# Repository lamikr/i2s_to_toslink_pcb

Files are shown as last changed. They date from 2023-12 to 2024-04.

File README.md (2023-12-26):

I2S to Toslink PCB

Kicad 7.0 schematic and PCB project for PCB that
can generate optical AES/EBU signal for Toslink audio adapter. PCB uses the
WM8805 chipset as a codec for transforming the signal from I2S to AES/EBU Toslink.

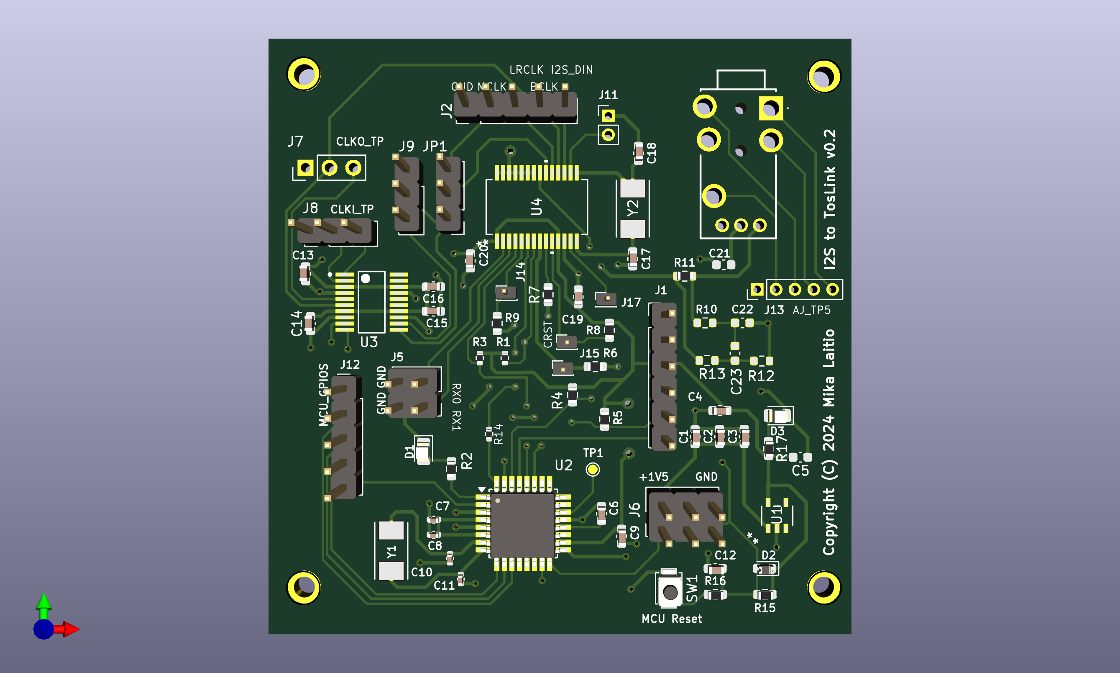
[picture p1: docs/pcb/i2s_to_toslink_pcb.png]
3D layout of PCB
 

PCB has following input pins:
- 5V power
- GND
- I2S data
- I2S LRCLK
- I2S BCLK
- I2S MCLK (optional)

PCB can either be configured to use the external MCLK or generate the MCLK from the BCLK.
Generation of MCLK is usually needed because the WM8805 does not always work with the external
MCLK and that is hearable as a small errors and cracks on audio.

Project will also need the firmware for ATmega chip so that it can configure the PLL generator
and WM8805 over I2C lines to right mode.

By default the WM8805 codec GPO0 and GPO7 are pulled down so that the WM8805 is configured to use 16 bit I2S data.
But those gpio's can be pulled also to UP to 3V3 voltage to configure the WM8805 to handle 24 bit I2S data if needed.
(see wm8805 docs for details). Codec can also be resetted externally via reset pin. (ATmega has free gpios with headers to drive those pins if you want to add the jumper wires and modify firmware)

[Schematics in PDF document](./docs/schematics/schematics.pdf)

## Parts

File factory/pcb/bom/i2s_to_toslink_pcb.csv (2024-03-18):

null | Sourced | Placed | References | Value | Footprint | Quantity
1 |  |  | C2, C4, C5, C6, C7, C8, C9, C12, C13, C14, C15, C16, C19, C20, C21 | 0u1F | C_0402_1005Metric | 15
2 | ✓ |  | C10, C11, C17, C18 | 16pF | C_0402_1005Metric | 4
3 | ✓ |  | C22, C23 | 0u1F | C_0603_1608Metric | 2
4 | ✓ |  | C1 | 4u7F | C_0402_1005Metric | 1
5 | ✓ |  | C3 | 1uF | C_0402_1005Metric | 1
6 | ✓ |  | R5, R6, R7, R8, R9 | 10k | R_0402_1005Metric | 5
7 | ✓ |  | R1, R3 | 4K7 | R_0402_1005Metric | 2
8 | ✓ |  | R10, R11 | 0 | R_0603_1608Metric | 2
9 | ✓ |  | R2 | 1K5 | R_0402_1005Metric | 1
10 | ✓ |  | R4 | 0k | R_0402_1005Metric | 1
11 | ✓ |  | R12 | 110 | R_0603_1608Metric | 1
12 | ✓ |  | R13 | 210 | R_0603_1608Metric | 1
13 |  |  | D1 | LED | LED_0805_2012Metric | 1
14 | ✓ |  | U1 | PTLV709A33DBVR | SOT-23-5_DBV_TEX | 1
15 | ✓ |  | U2 | ATmega168A-A | TQFP-32_7x7mm_P0.8mm | 1
16 |  |  | U3 | CDCE906PWR | PW0020A-IPC_A | 1
17 | ✓ |  | U4 | WM8805GEDS_V | SSOP28_WM8805GEDS_V_CIR | 1
18 |  |  | Y1 | 16M | XTAL_ABM7_ABR | 1
19 | ✓ |  | Y2 | 12M | XTAL_ABM7-12.000MHZ-D2Y-T | 1
20 |  |  | H1 | TL | MountingHole_2.2mm_M2_ISO7380_Pad_TopBottom | 1
21 |  |  | H2 | TR | MountingHole_2.2mm_M2_ISO7380_Pad_TopBottom | 1
22 |  |  | H3 | BL | MountingHole_2.2mm_M2_ISO7380_Pad_TopBottom | 1
23 |  |  | H4 | BR | MountingHole_2.2mm_M2_ISO7380_Pad_TopBottom | 1
24 |  |  | JP1 | MCLK_SEL | PinHeader_1x03_P2.54mm_Vertical | 1
25 |  |  | TP1 | TestPoint | TestPoint_Pad_D1.0mm | 1
26 |  |  | J1 | PWR IN | PinHeader_1x02_P2.54mm_Vertical | 1
27 |  |  | J2 | EXT_CLK_IN5 | PinHeader_1x05_P2.54mm_Vertical | 1
28 |  |  | J3 | PWR Test | PinHeader_1x03_P2.54mm_Vertical | 1
29 |  |  | J4 | MCU_GPIOS2 | PinHeader_1x03_P2.54mm_Vertical | 1
30 |  |  | J5 | FTDI_6P | PinHeader_1x06_P2.54mm_Vertical | 1
31 |  |  | J6 | AVR-ISP-6 | PinHeader_2x03_P2.54mm_Vertical | 1
32 |  |  | J7 | CLKI_3TP | PinHeader_1x03_P1.27mm_Vertical | 1
33 |  |  | J8 | SEL_3TP | PinHeader_1x03_P1.27mm_Vertical | 1
34 |  |  | J9 | CLKO_3TP | PinHeader_1x03_P1.27mm_Vertical | 1
35 | ✓ |  | J10 | FCR684204T | FCR684204T | 1
36 |  |  | J11 | DIN_DOUT_2TP | PinHeader_1x02_P1.27mm_Vertical | 1
37 |  |  | J12 | MCU_GPIOS1 | PinHeader_1x04_P2.54mm_Vertical | 1
38 |  |  | J13 | AJ_TP5 | PinHeader_1x05_P1.27mm_Vertical | 1
39 |  |  | J14 | C_G0 | PinHeader_1x01_P1.27mm_Vertical | 1
40 |  |  | J15 | C_G7 | PinHeader_1x01_P1.27mm_Vertical | 1
41 |  |  | J16 | C_RST | PinHeader_1x01_P1.27mm_Vertical | 1
42 |  |  | J17 | C_CLKOUT | PinHeader_1x01_P1.27mm_Vertical | 1

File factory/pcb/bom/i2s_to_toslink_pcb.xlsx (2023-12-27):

Reference | Value | Footprint | Datasheet | MFR | MPN | Notes | Price | QtyOrdered | SKU_DIGIKEY | Qty
C1 | 4u7F | Capacitor_SMD:C_0402_1005Metric | ~ | Murata | GRM155R60J475ME47D |  |  | 100 | 490-5915-1-ND | 1
C2, C4-C9, C12-C16, C19-C21 | 0u1F | Capacitor_SMD:C_0402_1005Metric | ~ | Murata | GRM033R61A104ME15D |  |  | 100 | 490-5405-1-ND | 15
C3 | 1uF | Capacitor_SMD:C_0402_1005Metric | ~ | Murata | GRM155R70J105KA12J |  |  | 100 | 490-13339-1-ND | 1
C10, C11, C17, C18 | 16pF | Capacitor_SMD:C_0402_1005Metric | ~ | Murata | GJM1555C1H160GB01D |  |  | 100 | 490-8081-1-ND | 4
C22, C23 | 0u1F | Capacitor_SMD:C_0603_1608Metric | ~ | Murata | GCJ188R71H104KA12D |  | 0.16 | 100 | 490-5798-1-ND | 2
J3 | PWR Test | Connector_PinHeader_2.54mm:PinHeader_1x03_P2.54mm_Vertical | ~ | Würth Elektronik | 61300311121 |  | 0.13 | 25 | 732-5316-ND | 1
J5 | FTDI_6P | Connector_PinHeader_2.54mm:PinHeader_1x06_P2.54mm_Vertical | ~ | Amphenol ICC | 10129378-920001BLF-ND | 1x20 | 0.43 | 10 | 10129378-920001BLF-ND | 1
J6 | AVR-ISP-6 | Connector_PinHeader_2.54mm:PinHeader_2x03_P2.54mm_Vertical | ~ | Amphenol ICC | 75869-131LF | 2x3 with plastic | 0.88 | 5 | 609-2845-ND | 1
J10 | FCR684204T | FCR684204T | ~ | CLIFF ELECTRONIC COMPONENTS | FCR684204T |  | 4.22 | 3 | 4654-FCR684204T-ND | 1
J11 | DIN_DOUT_2TP | Connector_PinHeader_1.27mm:PinHeader_1x02_P1.27mm_Vertical | ~ | Adam Tech | HPH1-A-20-UA | 1x20 pin header | 0.72 | 10 | 2057-HPH1-A-20-UA-ND | 1
J13 | AJ_TP5 | Connector_PinHeader_1.27mm:PinHeader_1x05_P1.27mm_Vertical | ~ | Sullins Connector Solutions | S9014E-05-ND |  | 0.4 | 10 | GRPB051VWVN-RC | 1
R1, R3 | 4K7 | Resistor_SMD:R_0402_1005Metric | ~ | Yageo | RC0402FR-074K7L |  | 0.1 | 100 | 311-4.7KLRCT-ND | 2
R2 | 1K5 | Resistor_SMD:R_0402_1005Metric | ~ | Yageo | RC0402FR-071K5L |  | 0.1 | 100 | 311-1.50KLRCT-ND | 1
R4 | 0k | Resistor_SMD:R_0402_1005Metric | ~ | Yageo | RC0402FR-070RL |  | 0.1 | 100 | 311-0.0LRCT-ND | 1
R5-R9 | 10k | Resistor_SMD:R_0402_1005Metric | ~ | Yageo | RC0402FR-0710KL |  | 0.1 | 100 | 311-10.0KLRCT-ND | 5
R10, R11 | 0 | Resistor_SMD:R_0603_1608Metric | ~ | Yageo | RC0603JR-070RL |  | 0.1 | 100 | 311-0.0GRCT-ND | 2
R12 | 110 | Resistor_SMD:R_0603_1608Metric | ~ | Yageo | RC0603JR-07110RL |  | 0.1 | 100 | 311-110GRCT-ND | 1
R13 | 210 | Resistor_SMD:R_0603_1608Metric | ~ | Yageo | RC0603FR-07210RL |  | 0.1 | 100 | 311-210HRCT-ND | 1
U1 | TLV709A33DBVR | SOT-23-5_DBV_TEX | ~ | TI | TLV709A33DBVR |  | 0.76 | 10 | 296-TLV709A33DBVRDKR-ND | 1
U2 | ATmega168A-A | Package_QFP:TQFP-32_7x7mm_P0.8mm | ~ | Microshell | ATMEGA168A-AUR |  | 2.36 | 3 | ATMEGA168A-AURCT-ND | 1
U3 | CDCE906PWR | PW0020A-IPC_A | ~ | TI | CDCE906PWR |  | 5.18 | 3 | 296-26038-1-ND | 1
U4 | WM8805GEDS_V | SSOP28_WM8805GEDS_V_CIR | ~ | Cirrus Logic | WM8805GEDS_V |  | 12 | 3 | 598-2396-ND | 1
Y1 | 16M | lamikr_audio:XTAL_ABM7_ABR | ~ | Abracon LLC | ABM7-16.000MHZ-D2Y-T |  | 0.67 | 10 | 535-9840-1-ND | 1
Y2 | 12M | lamikr_audio:XTAL_ABM7-12.000MHZ-D2Y-T | ~ | Abracon LLC | ABM7-12.000MHZ-D2Y-T |  | 0.67 | 10 | 535-9836-1-ND | 1

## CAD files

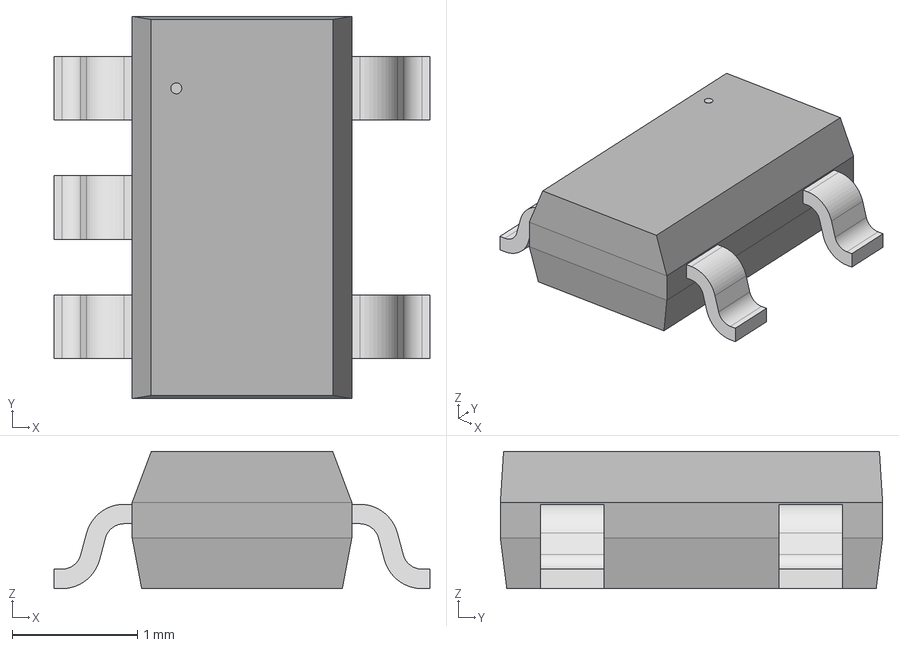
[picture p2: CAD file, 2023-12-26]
component_library/3dshapes/SOT-23-5_DBV_TEX.stp
3.00 x 3.05 x 1.09 mm

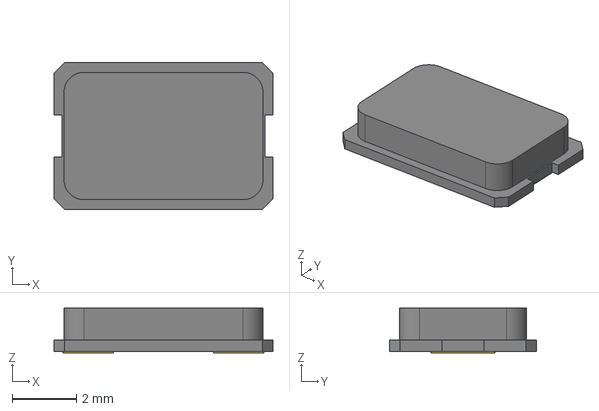
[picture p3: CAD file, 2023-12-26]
component_library/3dshapes/XTAL_ABM7_ABR.stp
6.82 x 4.58 x 1.40 mm

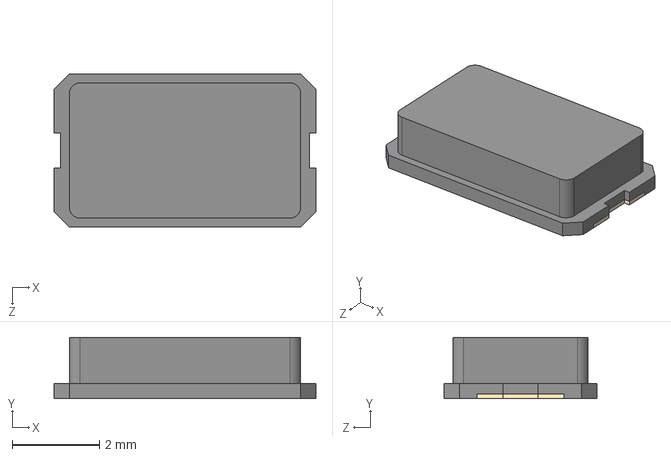
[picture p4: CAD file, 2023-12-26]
component_library/3dshapes/ABM7-12.000MHZ-D2Y-T.stp
6.00 x 1.40 x 3.50 mm

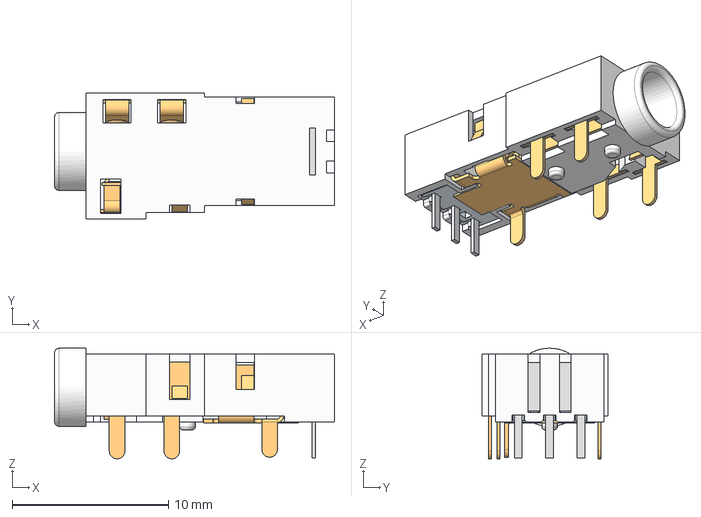
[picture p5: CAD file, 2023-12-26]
component_library/3dshapes/FCR684204T.stp
17.9 x 8.05 x 7.08 mm

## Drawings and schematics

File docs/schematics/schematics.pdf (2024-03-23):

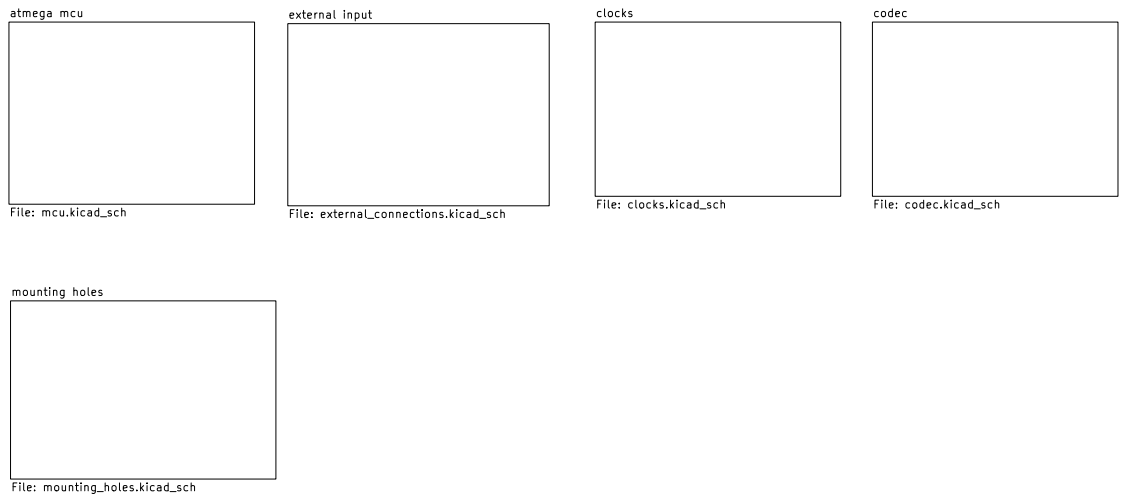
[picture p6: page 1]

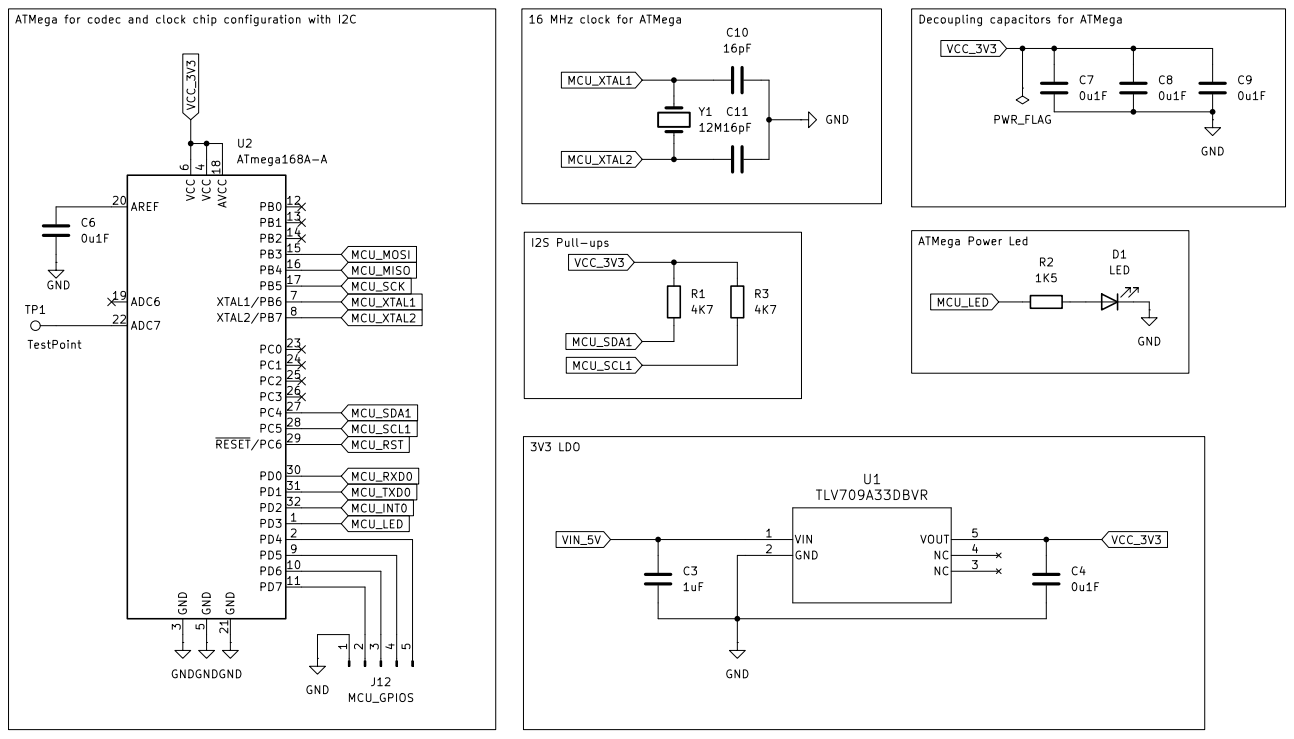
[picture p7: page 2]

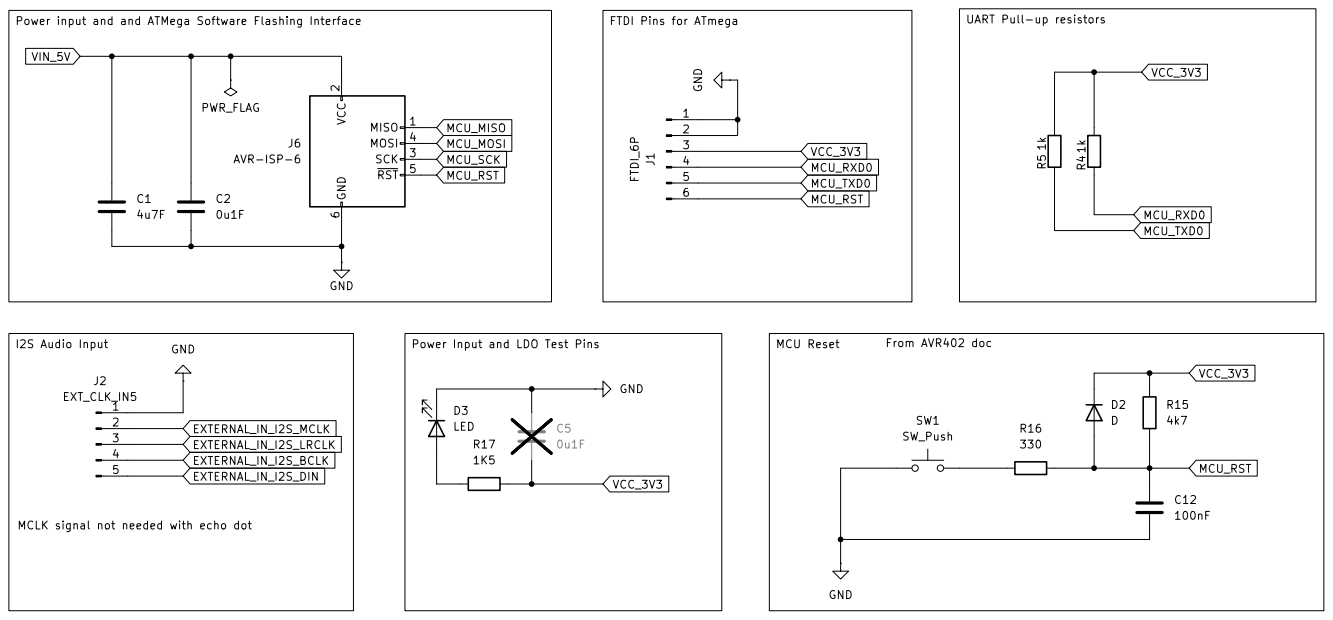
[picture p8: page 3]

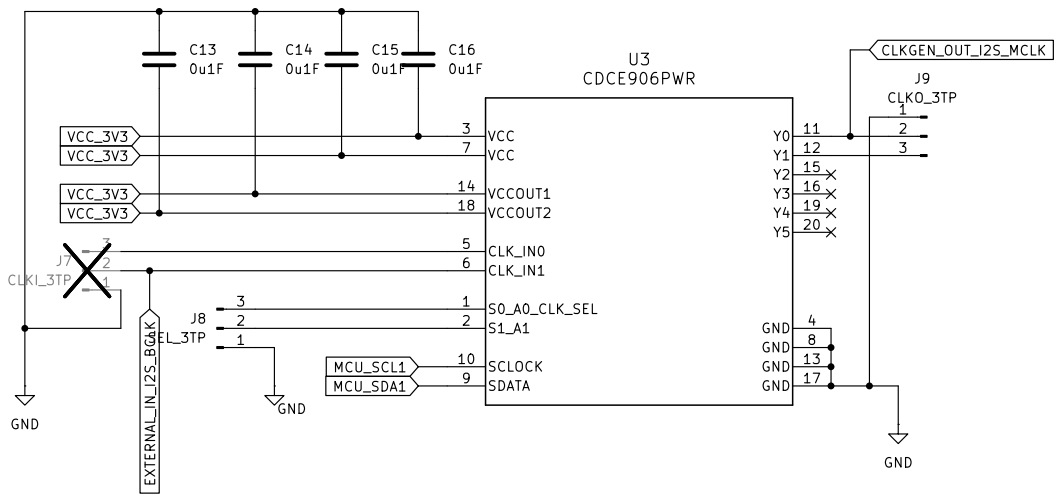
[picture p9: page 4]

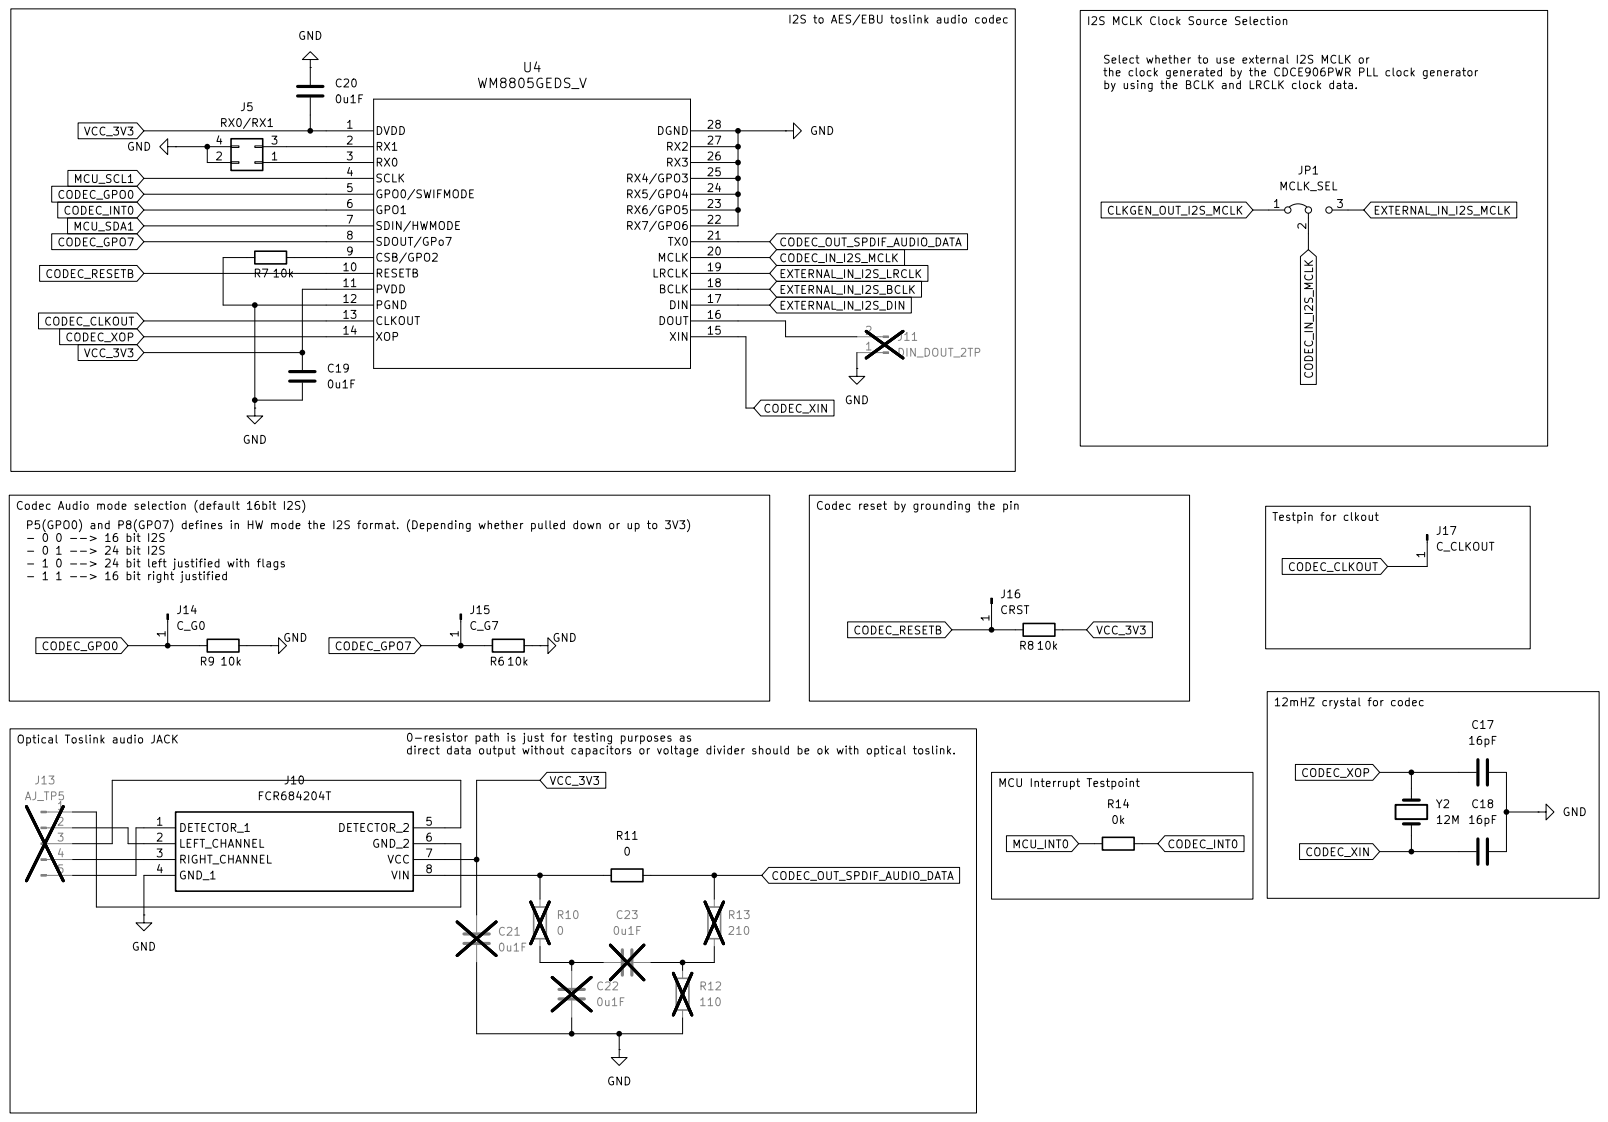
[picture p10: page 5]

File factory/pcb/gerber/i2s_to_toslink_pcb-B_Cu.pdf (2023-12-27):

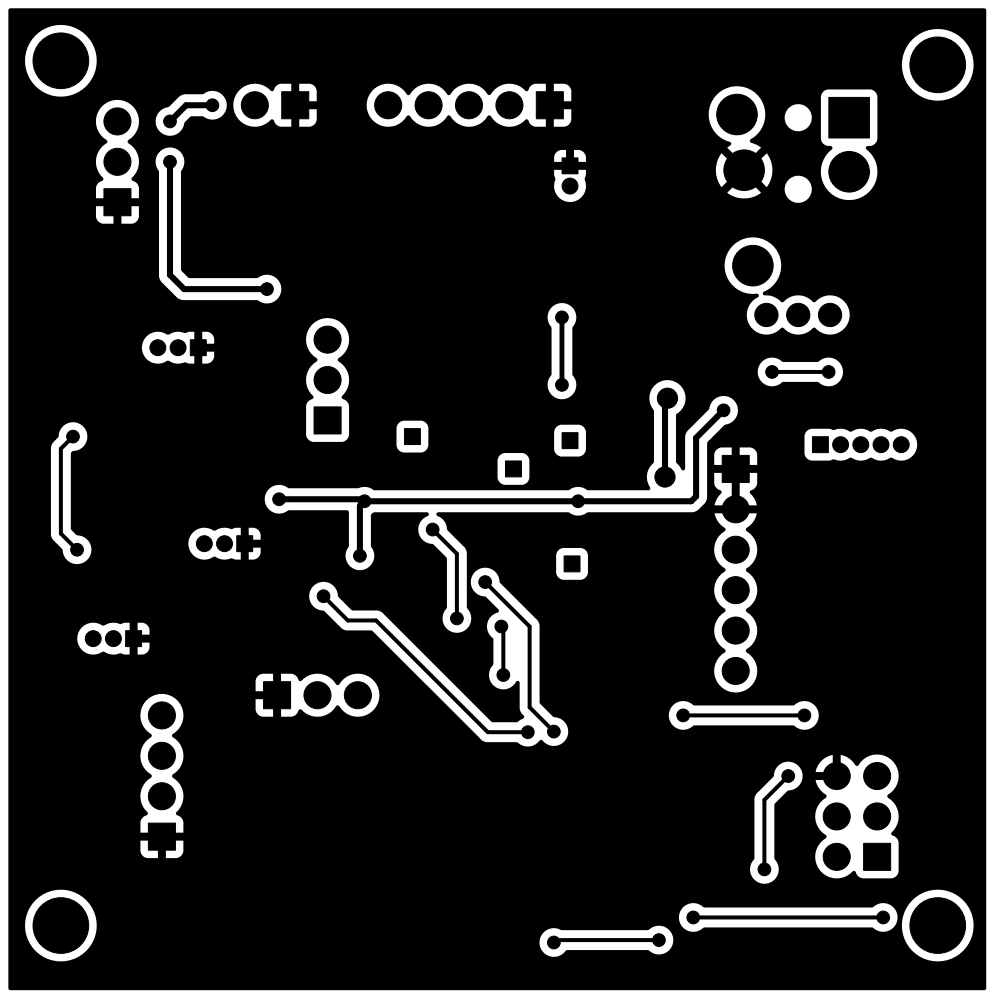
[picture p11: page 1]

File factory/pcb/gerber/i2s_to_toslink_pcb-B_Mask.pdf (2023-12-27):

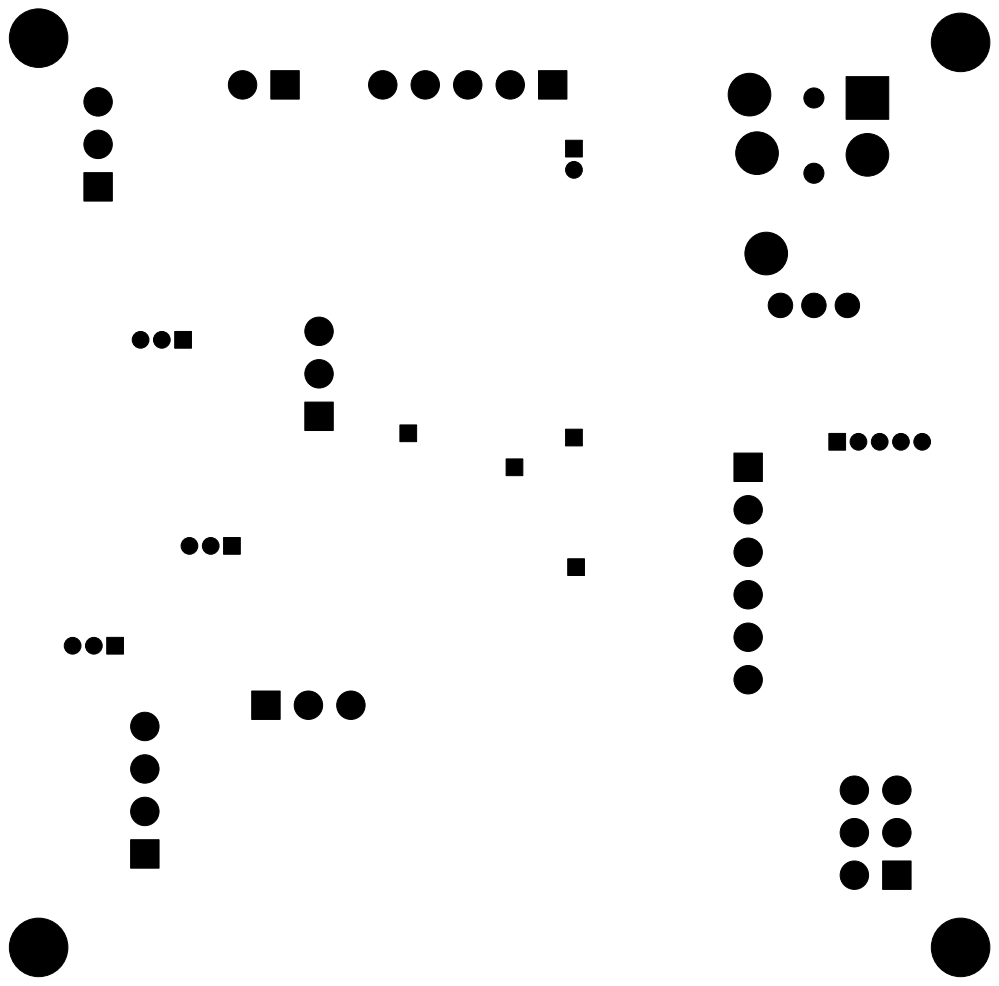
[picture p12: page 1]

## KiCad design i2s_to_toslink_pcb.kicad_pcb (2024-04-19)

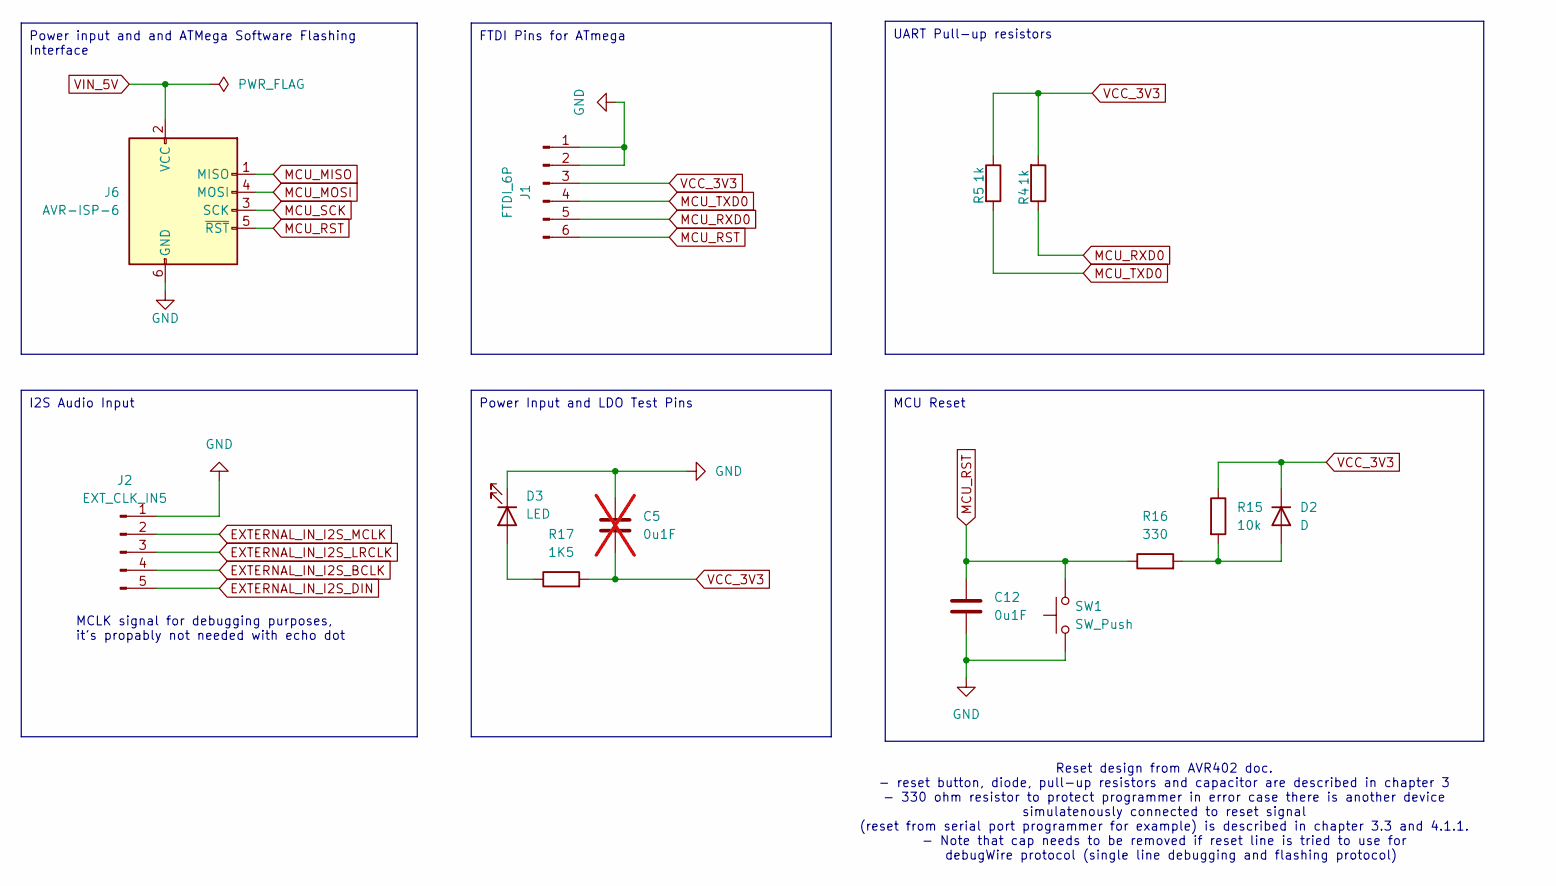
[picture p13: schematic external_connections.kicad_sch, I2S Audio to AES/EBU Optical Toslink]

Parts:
C5: 0u1F; C_0603_1608Metric; MPN GRM033R61A104ME15D; not fitted
C12: 0u1F; C_0603_1608Metric
D2: D; D_0603_1608Metric
D3: LED; LED_0805_2012Metric; MPN QBLP631-AG
J1: FTDI_6P; PinHeader_1x06_P2.54mm_Vertical; MPN 10129378-920001BLF-ND
J2: EXT_CLK_IN5; PinHeader_1x05_P2.54mm_Vertical
J6: AVR-ISP-6; PinHeader_2x03_P2.54mm_Vertical; MPN 75869-131LF
R4: 1k; R_0603_1608Metric; MPN RC0402FR-0710KL
R5: 1k; R_0603_1608Metric; MPN RC0402FR-070RL
R15: 10k; R_0603_1608Metric
R16: 330; R_0603_1608Metric
R17: 1K5; R_0603_1608Metric; MPN RC0402FR-071K5L
SW1: SW_Push; SW_SPST_B3U-1000P

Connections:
EXTERNAL_IN_I2S_BCLK: J2.4; also elsewhere on the board
EXTERNAL_IN_I2S_DIN: J2.5; also elsewhere on the board
EXTERNAL_IN_I2S_LRCLK: J2.3; also elsewhere on the board
EXTERNAL_IN_I2S_MCLK: J2.2; also elsewhere on the board
GND: C5.1, C12.2, D3.1 (K), J1.1, J1.2, J2.1, J6.6 (GND), SW1.1; also elsewhere on the board
MCU_MISO: J6.1 (MISO); also elsewhere on the board
MCU_MOSI: J6.4 (MOSI); also elsewhere on the board
MCU_RST: C12.1, J1.6, J6.5 (~RST), R16.1, SW1.2; also elsewhere on the board
MCU_RXD0: J1.5, R4.1; also elsewhere on the board
MCU_SCK: J6.3 (SCK); also elsewhere on the board
MCU_TXD0: J1.4, R5.2; also elsewhere on the board
unnamed: D2.2 (A), R15.2, R16.2
unnamed: D3.2 (A), R17.1
VCC_3V3: C5.2, D2.1 (K), J1.3, R4.2, R5.1, R15.1, R17.2; also elsewhere on the board
VIN_5V: J6.2 (VCC); also elsewhere on the board

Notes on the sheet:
Power input and and ATMega Software Flashing Interface
MCU Reset
UART Pull-up resistors
FTDI Pins for ATmega
I2S Audio Input
Power Input and LDO Test Pins
MCLK signal for debugging purposes, it's propably not needed with echo dot
Reset design from AVR402 doc. - reset button, diode, pull-up resistors and capacitor are described in chapter 3 - 330 ohm resistor to protect programmer in error case there is another device simulatenously connected to reset signal (reset from serial port programmer for example) is described in cha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

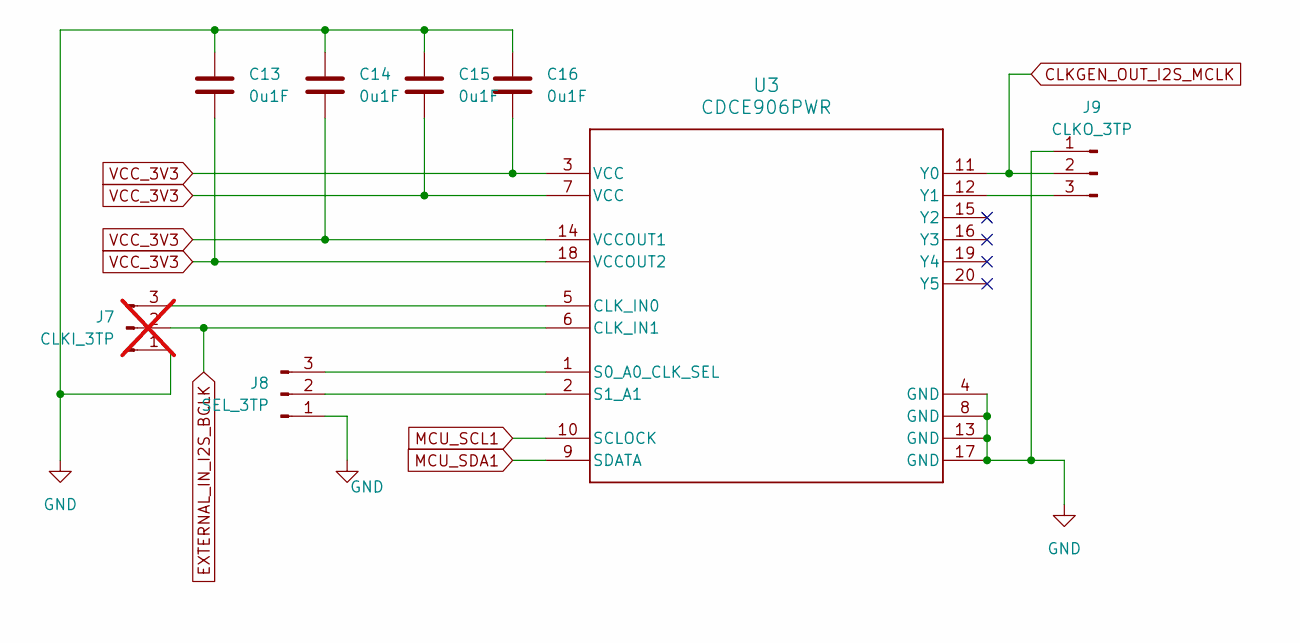
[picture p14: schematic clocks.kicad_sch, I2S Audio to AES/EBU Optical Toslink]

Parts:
C13, C14, C15, C16: 0u1F; C_0603_1608Metric; MPN GRM033R61A104ME15D
J7: CLKI_3TP; PinHeader_1x03_P2.54mm_Vertical; not fitted
J8: SEL_3TP; PinHeader_1x03_P2.54mm_Vertical
J9: CLKO_3TP; PinHeader_1x03_P2.54mm_Vertical
U3: CDCE906PWR; PW0020A-IPC_A; MPN CDCE906PWR

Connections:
CLKGEN_OUT_I2S_MCLK: J9.2, U3.11 (Y0); also elsewhere on the board
EXTERNAL_IN_I2S_BCLK: J7.2, U3.6 (CLK_IN1); also elsewhere on the board
GND: C13.1, C14.1, C15.1, C16.1, J7.1, J8.1, J9.1, U3.4 (GND), U3.8 (GND), U3.13 (GND), U3.17 (GND); also elsewhere on the board
MCU_SCL1: U3.10 (SCLOCK); also elsewhere on the board
MCU_SDA1: U3.9 (SDATA); also elsewhere on the board
unnamed: J7.3, U3.5 (CLK_IN0)
unnamed: J8.2, U3.2 (S1_A1)
unnamed: J8.3, U3.1 (S0_A0_CLK_SEL)
unnamed: J9.3, U3.12 (Y1)
VCC_3V3: C13.2, C14.2, C15.2, C16.2, U3.3 (VCC), U3.7 (VCC), U3.14 (VCCOUT1), U3.18 (VCCOUT2); also elsewhere on the board

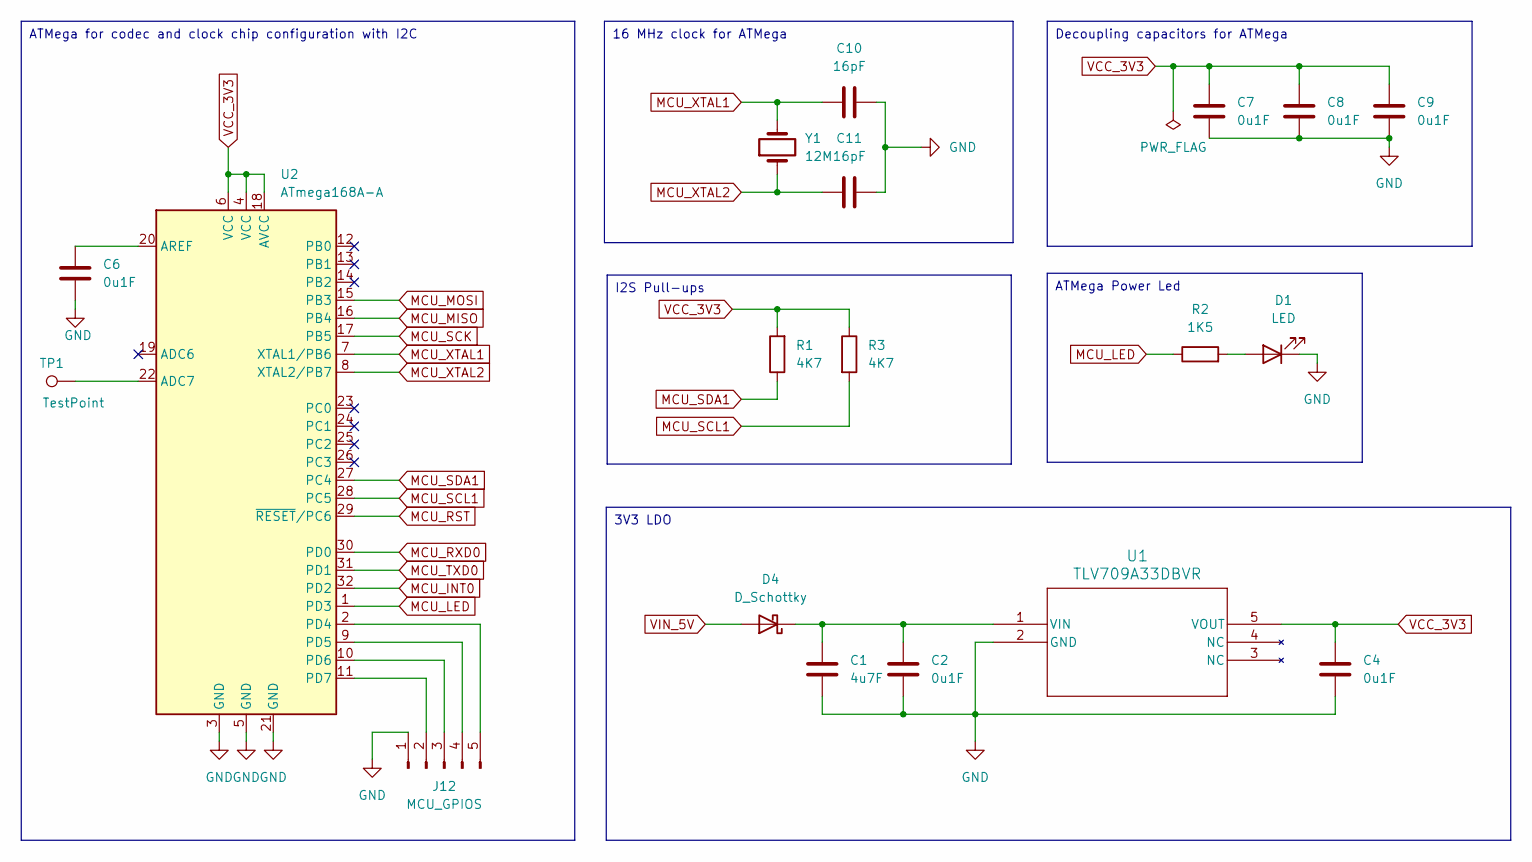
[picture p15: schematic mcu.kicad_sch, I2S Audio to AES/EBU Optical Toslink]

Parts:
C1: 4u7F; C_0603_1608Metric; MPN GRM155R60J475ME47D
C2, C4, C6, C7, C8, C9: 0u1F; C_0603_1608Metric; MPN GRM033R61A104ME15D
C10, C11: 16pF; C_0402_1005Metric; MPN GJM1555C1H160GB01D
D1: LED; LED_0805_2012Metric; MPN QBLP631-AG
D4: D_Schottky; D_0603_1608Metric
J12: MCU_GPIOS; PinHeader_1x05_P2.54mm_Vertical
R1, R3: 4K7; R_0603_1608Metric; MPN RC0402FR-074K7L
R2: 1K5; R_0603_1608Metric; MPN RC0402FR-071K5L
TP1: TestPoint; TestPoint_Pad_D1.0mm
U1: TLV709A33DBVR; SOT-23-5_DBV_TEX; MPN TLV709A33DBVR
U2: ATmega168A-A; TQFP-32_7x7mm_P0.8mm; MPN ATMEGA168A-AUR
Y1: 12M; XTAL_ABM7-12.000MHZ-D2Y-T; MPN ABM7-12.000MHZ-D2Y-T

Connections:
GND: C1.2, C2.2, C4.2, C6.2, C7.2, C8.2, C9.2, C10.2, C11.2, D1.1 (K), J12.1, U1.2 (GND), U2.3 (GND), U2.5 (GND), U2.21 (GND); also elsewhere on the board
MCU_INT0: U2.32 (PD2); also elsewhere on the board
MCU_LED: R2.1, U2.1 (PD3)
MCU_MISO: U2.16 (PB4); also elsewhere on the board
MCU_MOSI: U2.15 (PB3); also elsewhere on the board
MCU_RST: U2.29 (~RESET/PC6); also elsewhere on the board
MCU_RXD0: U2.30 (PD0); also elsewhere on the board
MCU_SCK: U2.17 (PB5); also elsewhere on the board
MCU_SCL1: R3.2, U2.28 (PC5); also elsewhere on the board
MCU_SDA1: R1.1, U2.27 (PC4); also elsewhere on the board
MCU_TXD0: U2.31 (PD1); also elsewhere on the board
MCU_XTAL1: C10.1, U2.7 (XTAL1/PB6), Y1.2
MCU_XTAL2: C11.1, U2.8 (XTAL2/PB7), Y1.1
unnamed: D1.2 (A), R2.2
unnamed: C1.1, C2.1, D4.1 (K), U1.1 (VIN)
unnamed: J12.2, U2.11 (PD7)
unnamed: J12.3, U2.10 (PD6)
unnamed: J12.4, U2.9 (PD5)
unnamed: J12.5, U2.2 (PD4)
unnamed: TP1.1, U2.22 (ADC7)
unnamed: C6.1, U2.20 (AREF)
VCC_3V3: C4.1, C7.1, C8.1, C9.1, R1.2, R3.1, U1.5 (VOUT), U2.4 (VCC), U2.6 (VCC), U2.18 (AVCC); also elsewhere on the board
VIN_5V: D4.2 (A); also elsewhere on the board

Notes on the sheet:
16 MHz clock for ATMega
ATMega for codec and clock chip configuration with I2C
ATMega Power Led
I2S Pull-ups
3V3 LDO
Decoupling capacitors for ATMega

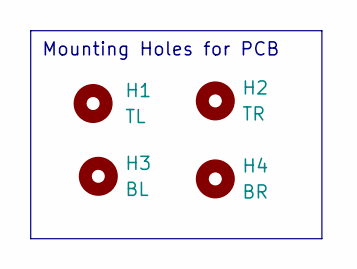
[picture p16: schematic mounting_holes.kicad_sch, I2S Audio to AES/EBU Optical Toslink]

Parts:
H1: TL; MountingHole_2.2mm_M2_ISO7380_Pad_TopBottom
H2: TR; MountingHole_2.2mm_M2_ISO7380_Pad_TopBottom
H3: BL; MountingHole_2.2mm_M2_ISO7380_Pad_TopBottom
H4: BR; MountingHole_2.2mm_M2_ISO7380_Pad_TopBottom

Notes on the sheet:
Mounting Holes for PCB

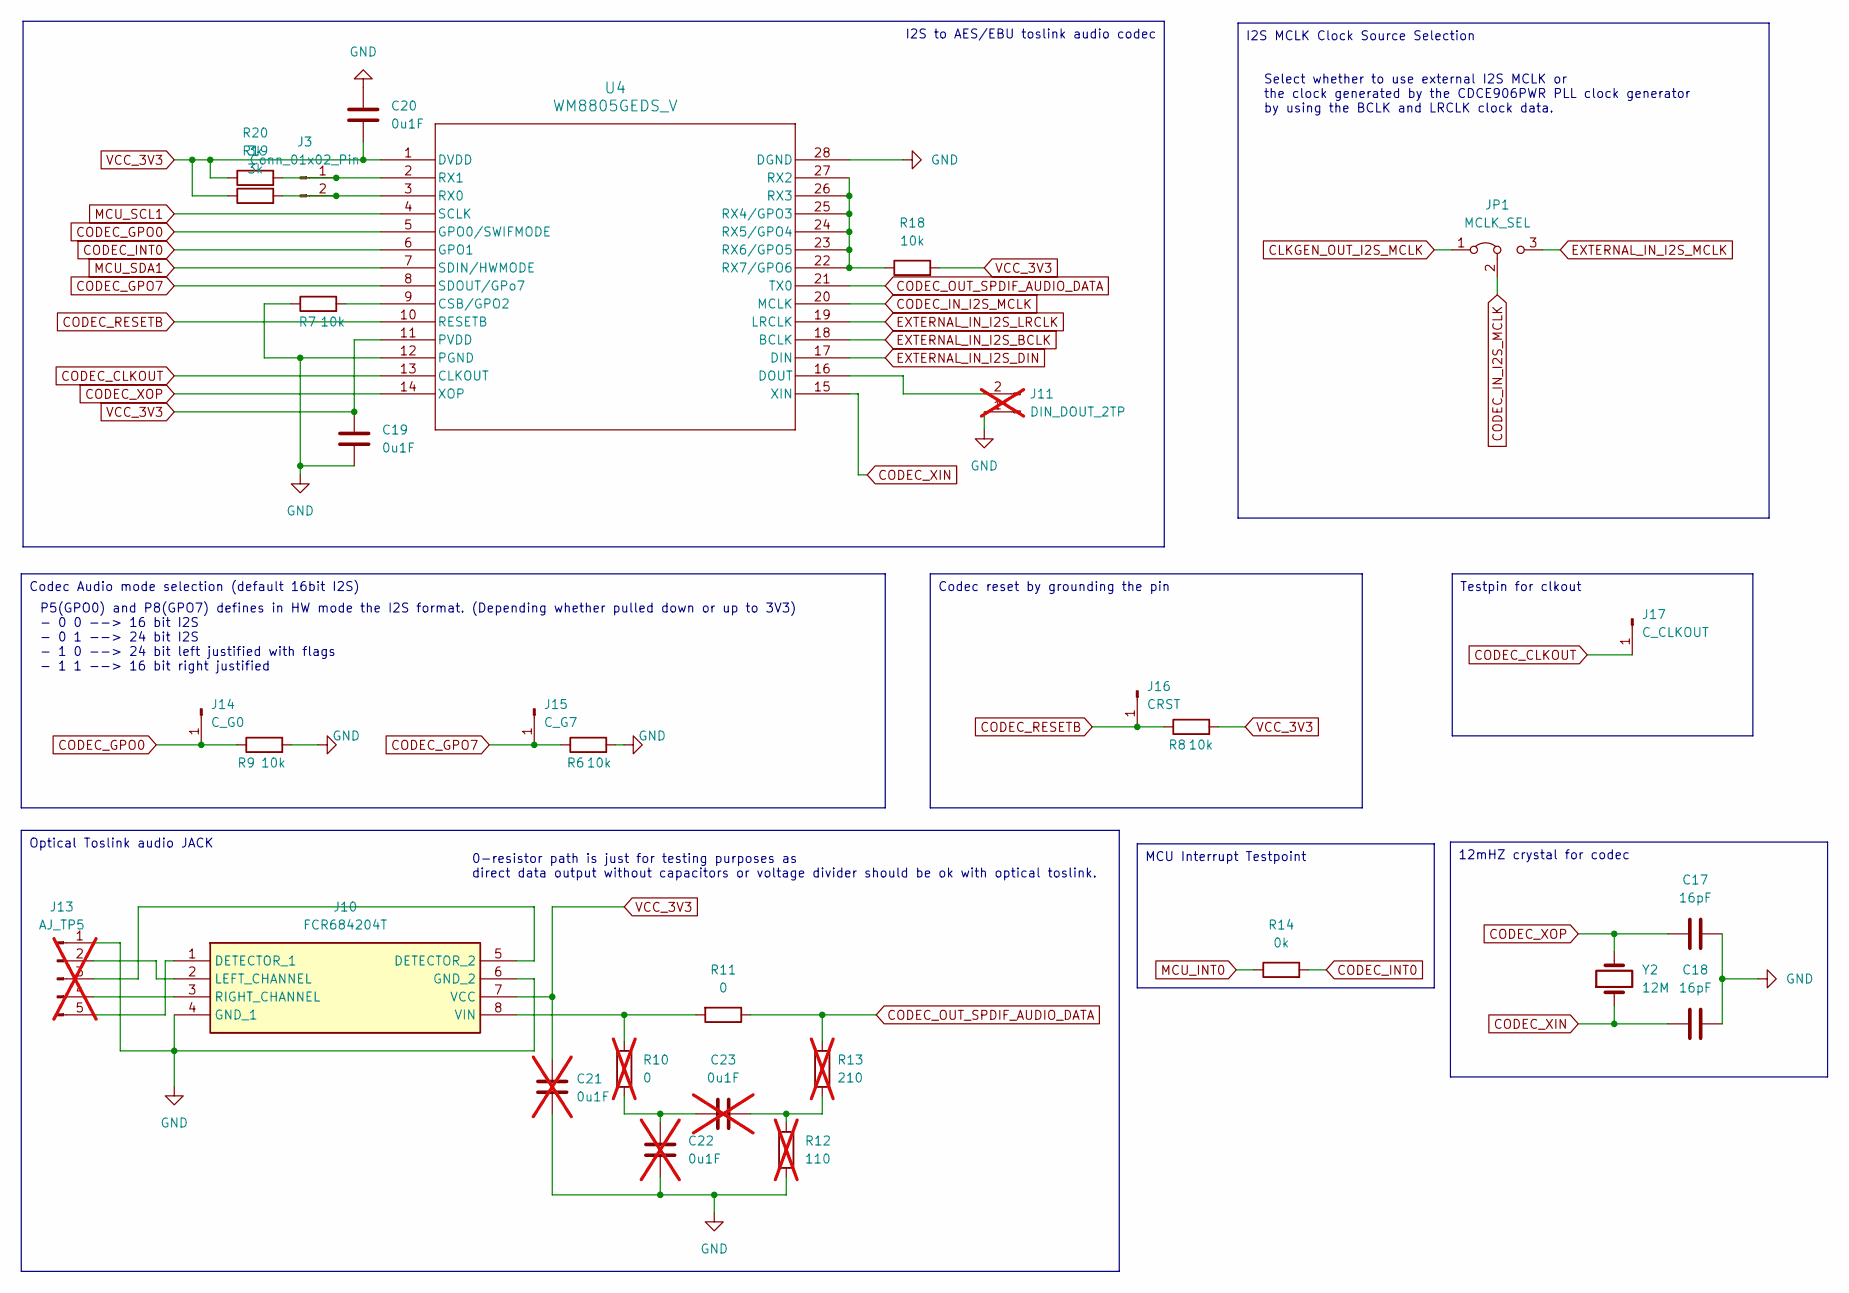
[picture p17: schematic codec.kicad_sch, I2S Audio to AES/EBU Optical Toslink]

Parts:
C17, C18: 16pF; C_0603_1608Metric; MPN GJM1555C1H160GB01D
C19, C20: 0u1F; C_0603_1608Metric; MPN GRM033R61A104ME15D
C21: 0u1F; C_0603_1608Metric; MPN GRM033R61A104ME15D; not fitted
C22, C23: 0u1F; C_0603_1608Metric; MPN GCJ188R71H104KA12D; not fitted
J3: Conn_01x02_Pin; PinHeader_1x02_P2.54mm_Vertical
J10: FCR684204T; MPN FCR684204T
J11: DIN_DOUT_2TP; PinHeader_1x02_P2.00mm_Vertical; MPN HPH1-A-20-UA; not fitted
J13: AJ_TP5; PinHeader_1x05_P2.00mm_Vertical; MPN S9014E-05-ND; not fitted
J14: C_G0; PinHeader_1x01_P1.27mm_Vertical
J15: C_G7; PinHeader_1x01_P1.27mm_Vertical
J16: CRST; PinHeader_1x01_P1.27mm_Vertical
J17: C_CLKOUT; PinHeader_1x01_P1.27mm_Vertical
JP1: MCLK_SEL; PinHeader_1x03_P2.54mm_Vertical
R6, R7, R8, R9: 10k; R_0603_1608Metric; MPN RC0402FR-0710KL
R10: 0; R_0603_1608Metric; MPN RC0603JR-070RL; not fitted
R11: 0; R_0603_1608Metric; MPN RC0603JR-070RL
R12: 110; R_0603_1608Metric; MPN RC0603JR-07110RL; not fitted
R13: 210; R_0603_1608Metric; MPN RC0603FR-07210RL; not fitted
R14: 0k; R_0603_1608Metric
R18: 10k; R_0603_1608Metric
R19, R20: 3k; R_0603_1608Metric
U4: WM8805GEDS_V; SSOP28_WM8805GEDS_V_CIR; MPN WM8805GEDS_V
Y2: 12M; XTAL_ABM7-12.000MHZ-D2Y-T; MPN ABM7-12.000MHZ-D2Y-T

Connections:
CLKGEN_OUT_I2S_MCLK: JP1.1 (A); also elsewhere on the board
CODEC_CLKOUT: J17.1, U4.13 (CLKOUT)
CODEC_GPO0: J14.1, R9.1, U4.5 (GPO0/SWIFMODE)
CODEC_GPO7: J15.1, R6.1, U4.8 (SDOUT/GPo7)
CODEC_INT0: R14.2, U4.6 (GPO1)
CODEC_IN_I2S_MCLK: JP1.2 (C), U4.20 (MCLK)
CODEC_OUT_SPDIF_AUDIO_DATA: R11.1, R13.2, U4.21 (TX0)
CODEC_RESETB: J16.1, R8.1, U4.10 (RESETB)
CODEC_XIN: C18.1, U4.15 (XIN), Y2.1
CODEC_XOP: C17.1, U4.14 (XOP), Y2.2
EXTERNAL_IN_I2S_BCLK: U4.18 (BCLK); also elsewhere on the board
EXTERNAL_IN_I2S_DIN: U4.17 (DIN); also elsewhere on the board
EXTERNAL_IN_I2S_LRCLK: U4.19 (LRCLK); also elsewhere on the board
EXTERNAL_IN_I2S_MCLK: JP1.3 (B); also elsewhere on the board
GND: C17.2, C18.2, C19.2, C20.1, C21.2, C22.2, J10.4 (GND_1), J10.6 (GND_2), J11.1, J13.1, R6.2, R7.1, R9.2, R12.2, U4.12 (PGND), U4.28 (DGND); also elsewhere on the board
MCU_INT0: R14.1; also elsewhere on the board
MCU_SCL1: U4.4 (SCLK); also elsewhere on the board
MCU_SDA1: U4.7 (SDIN/HWMODE); also elsewhere on the board
unnamed: C22.1, C23.1, R10.2
unnamed: C23.2, R12.1, R13.1
unnamed: J3.1, R20.2, U4.2 (RX1)
unnamed: J3.2, R19.2, U4.3 (RX0)
unnamed: J10.1 (DETECTOR_1), J13.5
unnamed: J10.5 (DETECTOR_2), J13.3
unnamed: J10.2 (LEFT_CHANNEL), J13.2
unnamed: J10.3 (RIGHT_CHANNEL), J13.4
unnamed: J10.8 (VIN), R10.1, R11.2
unnamed: J11.2, U4.16 (DOUT)
unnamed: R7.2, U4.9 (CSB/GPO2)
unnamed: R18.1, U4.22 (RX7/GPO6), U4.23 (RX6/GPO5), U4.24 (RX5/GPO4), U4.25 (RX4/GPO3), U4.26 (RX3), U4.27 (RX2)
VCC_3V3: C19.1, C20.2, C21.1, J10.7 (VCC), R8.2, R18.2, R19.1, R20.1, U4.1 (DVDD), U4.11 (PVDD); also elsewhere on the board

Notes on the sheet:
MCU Interrupt Testpoint
Optical Toslink audio JACK
12mHZ crystal for codec
Codec Audio mode selection (default 16bit I2S)
Codec reset by grounding the pin
Testpin for clkout
I2S to AES/EBU toslink audio codec
I2S MCLK Clock Source Selection
Select whether to use external I2S MCLK or the clock generated by the CDCE906PWR PLL clock generator by using the BCLK and LRCLK clock data.
P5(GPO0) and P8(GPO7) defines in HW mode the I2S format. (Depending whether pulled down or up to 3V3) - 0 0 --> 16 bit I2S - 0 1 --> 24 bit I2S - 1 0 --> 24 bit left justified with flags - 1 1 --> 16 bit right justified
0-resistor path is just for testing purposes as direct data output without capacitors or voltage divider should be ok with optical toslink.

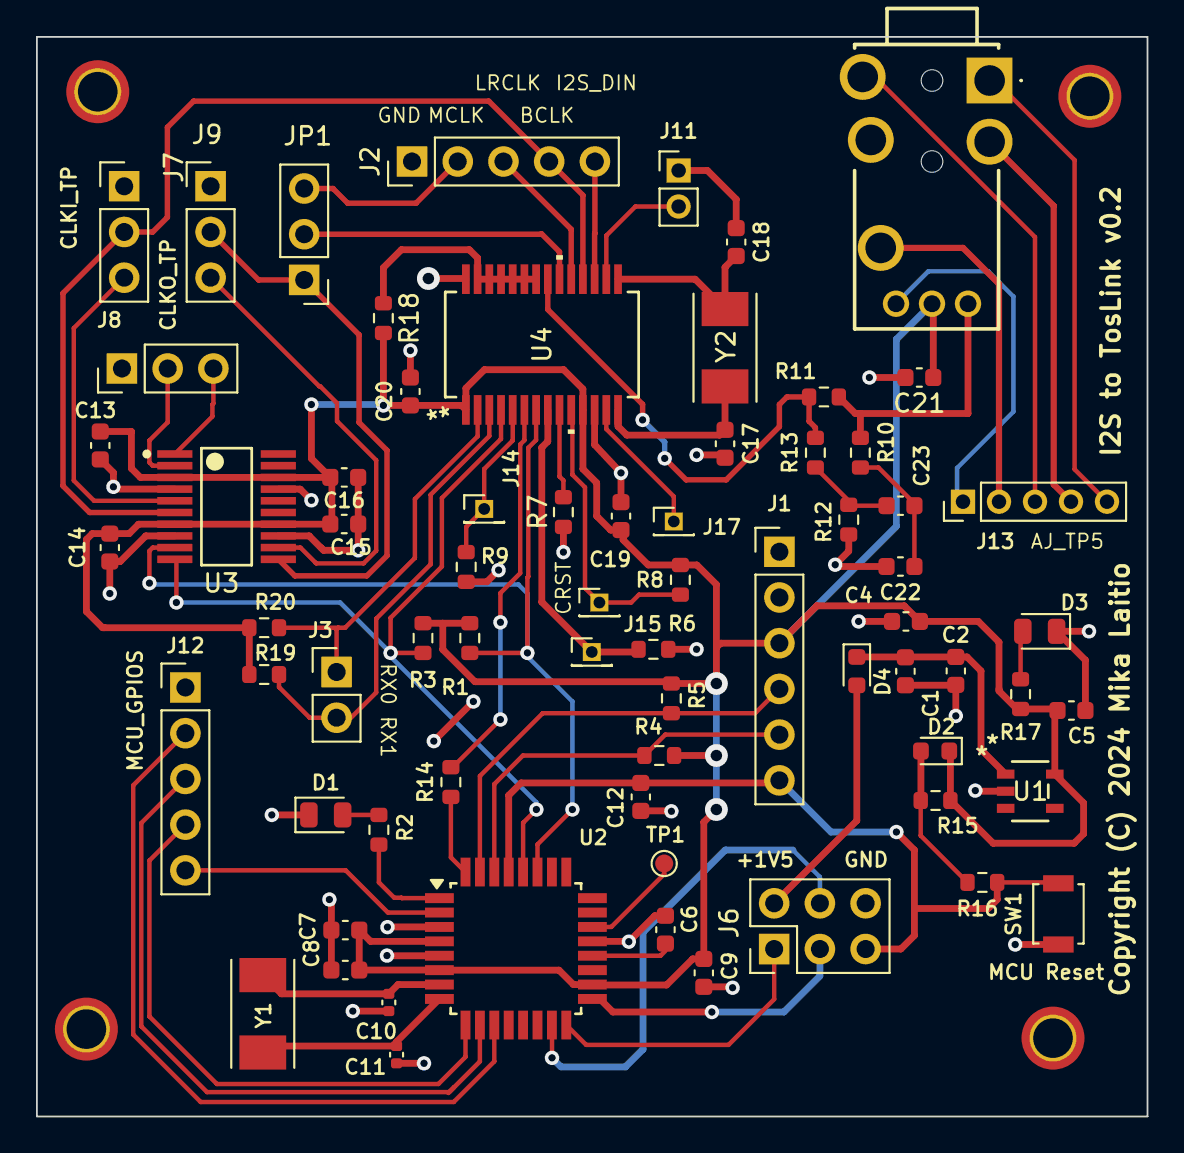
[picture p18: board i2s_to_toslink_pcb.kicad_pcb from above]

Board: 2 copper layers, 61.7 x 60.0 mm, 74 parts (0 on the bottom side), 55 nets.

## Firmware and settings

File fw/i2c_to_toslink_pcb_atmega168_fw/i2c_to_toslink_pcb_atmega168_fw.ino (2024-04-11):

/*
 * Copyright (c) 2024 Mika Laitio <lamikr@gmail.com>
 * 
 * This firmware is for the atmega168 located in i2c_to_toslink_pcb.
 * It's purpose is to initialize the cdcd906 so that it can generate the mclk clock
 * from other i2s clocks available. MCLK and other i2s clocks + datasignal are then feed
 * to wm8805 which will convert the i2s signal to optical toslink signal.
 *
 */

#include <Wire.h>

#define F_CPU 12000000UL
#define BAUD 12800UL

#define LED_PIN A0
#define I2C_ADDR__CDCE906 0x69
#define I2C_ADDR__WM8805  0x3A

static bool setup_ok;

bool i2c_read_uint8(int devaddr,
                      uint8_t regaddr,
                      uint8_t *data,
                      bool cdce906_single_byte_rw_operation)
{
  bool ret;
  int res;

  ret = false;
  // cdce906 single byte read and write operations requires that 
  // the bit 7 of registry is set to 1
  // and bulk read and write operations requires that the bit 7 is set to 0.
  if (cdce906_single_byte_rw_operation == true) {
    // cdce906 specific single byte read or write operation
    regaddr |= (1 << 7);
  }
  Wire.beginTransmission(devaddr);
  Wire.write(regaddr);
  Wire.endTransmission(false);  // do not send stop connection after sending requested address
  Wire.requestFrom(devaddr, 1); // read the registry
  *data = Wire.read();
  res = Wire.endTransmission(true);
  if (res == 0) {
    ret = true;
  }
  return ret;
}

bool i2c_write_uint8(int devaddr,
                    uint8_t regaddr,
                    uint8_t dataval,
                    bool cdce906_single_byte_rw_operation) {
  int res;
  bool ret;

  ret = false;
  // cdce906 single byte read and write operations requires that 
  // the bit 7 of registry is set to 1
  // and bulk read and write operations requires that the bit 7 is set to 0.
  if (cdce906_single_byte_rw_operation == true) {
    // cdce906 specific single byte read or write operation
    regaddr |= (1 << 7);
  }
  // Write a data register value
  Wire.beginTransmission(devaddr); // device
  Wire.write(regaddr); // register
  Wire.write(dataval); // data
  res = Wire.endTransmission(true);
  if (res == 0) {
    ret = true;
  }
  return ret;
}

bool cdce906_init(uint8_t devaddr) {
  int ii;
  byte res_int;
  bool res;
  uint8_t data;
  bool ret;

  ret = false;
  Wire.beginTransmission(devaddr);
  res_int = Wire.endTransmission();
  if (res_int == 0) {
    Serial.print("CDCE906 found, i2c addr: 0x");
    Serial.println(devaddr, HEX);
    // Set "Input Signal Source"
    delay(200);
    res = i2c_read_uint8(devaddr, 11, &data, true);
    if (res == true) {
      Serial.print("Old input signal source: 0x");
      Serial.println(data, HEX);
      data |= 1 << 6;
      data &= ~(1 << 7);
      Serial.print("New input signal source: 0x");
      Serial.println(data, HEX);
      res = i2c_write_uint8(devaddr, 11, data, true);
      if (res == true) {
        // Set Input Clock Selection (byte10, bit 4)
        res = i2c_read_uint8(devaddr, 10, &data, true);
        if (res == true) {
          // set clock source to CLK_IN1/BCLK
          data |= 1 << 4;    // Clock source = CLK_IN1 (BCLK input)
          i2c_write_uint8(devaddr, 10, data, true);
          // configure PLL to be 4x input signal
          // Y0 used for MCLK gen signal
          // cdcd906 datasheet page 18
          // Default setting of divider P0 = 10, P1 = 20, P2 = 8, P3 = 9, P4 = 32, and P5 = 4
          // P2 used by default for Y0, Y1, Y2, Y3, Y4 and Y5
          // cdcd906 datasheet page 27
          // sample_freq_out = (sample_freq_in x N) / (M x P2) = sample_freq_in x 32 / (1 x 8) = sample_freq_in * 4        
          i2c_write_uint8(devaddr, 1, 1, true);  // PLL1, M = 1
          res = i2c_write_uint8(devaddr, 2, 32, true); // PLL1, N = 32
          if (res == true) {
            ret = true;
          }
        }
      }
    }
    else {
      Serial.print("cdce906 failed to write input signal source");
    }
  }
  else {
    Serial.print("cdce906 not found response from in i2c addr: 0x");
    Serial.print(devaddr, HEX);
    Serial.print(", err: ");
    Serial.println(res_int);
  }
  delay(200);
  res = i2c_read_uint8(devaddr, 0, &data, true);
  if (res == true) {
    Serial.print("VENDOR_ID_AND_REV: ");
    Serial.print(data);
    Serial.println("");
    Serial.print("  Vendor_ID: ");
    Serial.print(data & 0x0F);
    Serial.println("");
    Serial.print("  Rev_code: ");
    Serial.println((data & 0xF0) >> 4);
  }
  else {
    Serial.print("Failed to read vendor id and revision");
  }
  return ret;
}

bool wm8805_init(uint8_t devaddr) {
  int res_int;
  uint8_t data;
  bool res;
  bool ret;

  ret = false;
  Wire.beginTransmission(devaddr);
  res_int = Wire.endTransmission();
  if (res_int == 0) {
    Serial.print("WM8805 found, i2c addr: 0x");
    Serial.println(devaddr, HEX);
    Serial.print("Device ID: ");  
    res = i2c_read_uint8(devaddr, 1, &data, false);
    if (data < 10) {
      Serial.print('0');
    } 
    Serial.print(data, HEX);
    res = i2c_read_uint8(devaddr, 0, &data, false);
    if (data < 10) {
      Serial.print('0');
    } 
    Serial.print(data, HEX);
    res = i2c_read_uint8(devaddr, 2, &data, false);
    if (res == true) {
      Serial.print(" Rev. ");  
      Serial.println(data, HEX);
      delay(2000);
      // resets, initializes and powers a wm8805 reset device
      res = i2c_write_uint8(devaddr, 0, 0, false);
      if (res == true) {
        // REGISTER 30
        // set the PWRDN
        // bit 7:6 - always 0
        // bit   5 - TRIOP      - Tri-state all Outputs => 0
        // bit   4 - AIFPD      - Digital Audio Interface Power Down => 0
        // bit   3 - OSCPD      - Oscillator Power Down => 0
        // bit   2 - SPDIFTXPD  - S/PDIF Transmitter Powerdown => 0
        // bit   1 - SPDIFRXPD  - S/PDIF Receiver Powerdown => 1 (off)
        // bit   0 - PLLPD      - PLL Powerdown => 0
        res = i2c_write_uint8(devaddr, 30, B00001011, false);
        if (res == true) {
          ret = true;
        }
      }
    }  
  }
  else {
    Serial.print("WM8896 not found response from in i2c addr: 0x");
    Serial.print(devaddr, HEX);
    Serial.print(", err: ");
    Serial.println(res_int);
  }
  return ret;
}

void setup() {
  bool res;

  setup_ok = false;
  Serial.begin(BAUD);
  while (!Serial);
  pinMode(LED_PIN, OUTPUT);
  digitalWrite(LED_PIN, LOW);
  Wire.begin();
  delay(5000);
  res = cdce906_init(I2C_ADDR__CDCE906);
  if (res == true) {
    delay(1000);
    res = wm8805_init(I2C_ADDR__WM8805);
    if (res == true) {
      setup_ok = true;
      Serial.println("i2c devices initialized ok");
      digitalWrite(LED_PIN, HIGH);
    }
  }
}

void loop() {
  // in error cases blink the led slowly
  delay(10000);
  if (setup_ok == false) {
    digitalWrite(LED_PIN, HIGH);
  }
  delay(1000);
  if (setup_ok == false) {
    digitalWrite(LED_PIN, LOW);
  }
}

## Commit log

2023-12-26 initial schematics and pcb ready
    [ABM7-12.000MHZ-D2Y-T.stp, FCR684204T.stp, SOT-23-5_DBV_TEX.stp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]
2023-12-26 added version information
    [clocks.kicad_sch, codec.kicad_sch, external_connections.kicad_sch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]
2023-12-26 small text description for LDO
    [external_connections.kicad_sch]
2023-12-26 printed pdf from schematics
    [clocks.kicad_sch, codec.kicad_sch, external_connections.kicad_sch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]
2023-12-26 exported gerber and 3d pcb files
    [i2s_to_toslink_pcb-B_Cu.gbr, i2s_to_toslink_pcb-B_Mask.gbr, i2s_to_toslink_pcb-B_Paste.gbr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]
2023-12-26 small layout changes for some components
    [i2s_to_toslink_pcb.kicad_pcb]
2023-12-27 added mpn and sku_digikey numbers for bom
    [clocks.kicad_sch, codec.kicad_sch, external_connections.kicad_sch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]
2023-12-27 added led that was missing from bom
    [i2s_to_toslink_pcb.csv, mcu.kicad_sch]
2023-12-27 bomlink csv update
    [i2s_to_toslink_pcb.csv]
2023-12-27 change gerber file location
    [i2s_to_toslink_pcb-B_Cu.gbr, i2s_to_toslink_pcb-B_Mask.gbr, i2s_to_toslink_pcb-B_Paste.gbr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]
2023-12-27 optimized bom from digikey
    [clocks.kicad_sch, codec.kicad_sch, external_connections.kicad_sch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]
2024-01-18 cleaned up some vias not required
    [i2s_to_toslink_pcb-B_Cu.gbr, i2s_to_toslink_pcb-B_Mask.gbr, i2s_to_toslink_pcb-B_Paste.gbr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]
2024-01-18 added version label v0.1 to pcb
    [i2s_to_toslink_pcb-B_Cu.gbr, i2s_to_toslink_pcb-B_Mask.gbr, i2s_to_toslink_pcb-B_Paste.gbr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]
2024-02-08 10 percentage solder mask clearance
    - reduced the size of solder mask for
    CDCE906PWR, WM8805GEDS_V and ATMega168
    about 10 percentage. This will reduce the
    size of holes on pins very close to each others
    and thus help to spread the soldermask in a way
    that pins with soldermask will not touch
    to each others.
    [i2s_to_toslink_pcb-B_Cu.gbr, i2s_to_toslink_pcb-B_Mask.gbr, i2s_to_toslink_pcb-B_Paste.gbr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]
2024-03-18 ibom plugin files
    [i2s_to_toslink_pcb.csv]
2024-03-18 updated the symbol pin types
2024-03-18 various updates
    - removed duplicates 5V power connectors
    - now the whole pcb is always powered via 6 pin
    atmega avr isp connector
    - added connector for wm8805 rx0 and rx1
    - added labels for jumpers/connectors
    - moved the orientation of existing connecors
    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
    [clocks.kicad_sch, codec.kicad_sch, external_connections.kicad_sch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]
2024-03-19 finished v0.2 design
    - mcu ftdi serial connector reset pin
    to 3v3 instead of 5v
    - 3.3v pull-up resistor, cap and diode for mcu reset
    - mcu reset button
    - solder paste clearance -20% for
    mcu, codec, clk gen and ldo to help
    spreading pasta to small pins close to
    ech others
    [clocks.kicad_sch, codec.kicad_sch, external_connections.kicad_sch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]
2024-03-19 inceased the size of some tp headers to 2.00mm
    [codec.kicad_sch, external_connections.kicad_sch, i2s_to_toslink_pcb.kicad_pcb]
2024-03-21 component footprint updates
    - 0402 caps and resistors to 0603
    - reset pin-header to reset button
    [clocks.kicad_sch, codec.kicad_sch, external_connections.kicad_sch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]
2024-03-21 16M mcu crystal changed to 12M
    - Atmel168A crystal max frequency can be about
    13.3 Mhz for 3V3 voltage.
    See atmega168a datasheet Figure 29-1. Maximum Frequency vs. VCC
    --> 10MHz + 10Mhz/(4.5 - 2.7) * (3.3 - 2.7) = 13.3Mhz
    [i2s_to_toslink_pcb.kicad_pcb, mcu.kicad_sch]
2024-03-23 updated the kicad generated docs
    - schematics and 3d view of pcb
2024-03-24 add pull-up resistors for codex rx-pins
    - add connectors for rx0 and rx1 pins
    - rest of the rx-pins not reserved for use
    and they will share a common pull-up.
    [codec.kicad_sch, i2s_to_toslink_pcb.kicad_pcb, i2s_to_toslink_pcb.kicad_sch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]
2024-04-03 rework the atmega168 reset signal schematics and routing
    [codec.kicad_sch, external_connections.kicad_sch, i2s_to_toslink_pcb.kicad_pcb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]
2024-04-03 updated gerber and bom files
    [i2s_to_toslink_pcb-B_Cu.gbr, i2s_to_toslink_pcb-B_Mask.gbr, i2s_to_toslink_pcb-B_Paste.gbr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]
2024-04-11 esp32-c6-wroom-1 symbol and footprint
2024-04-11 esp32-s3 and esp32-c6-wroom-1 specs
2024-04-11 added atmega168a firmware
    - firmware for v0.1 pcb version
    (with some after ward reset line hw fixes...)
    - firmware can communicate and configure both the wm8805 and
    cdce906 chipsets over i2s.
    [i2c_to_toslink_pcb_atmega168_fw.ino]
2024-04-12 cleaned routing on C7 and C8 area
    [i2s_to_toslink_pcb.kicad_pcb]
2024-04-12 routing cleanups
    [i2s_to_toslink_pcb.kicad_pcb]
2024-04-19 fix toslink pin6 grounding
    - had problem already on v1 boards
    - move toslink/3.5mm plug little out of board
    - re-arrange alternative output
    [codec.kicad_sch, i2s_to_toslink_pcb.kicad_pcb]
